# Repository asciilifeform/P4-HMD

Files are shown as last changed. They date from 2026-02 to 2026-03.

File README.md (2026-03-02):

# Interface Board and Linux Support for Reflection Technology's "Private Eye P4" electromechanical HMD.

This project allows connecting the [Private Eye P4 head-mounted display](https://www.loper-os.org/?p=752) to an RPI-compatible Linux machine via an FPGA interface [board](/pcb/p4_pcb.png).

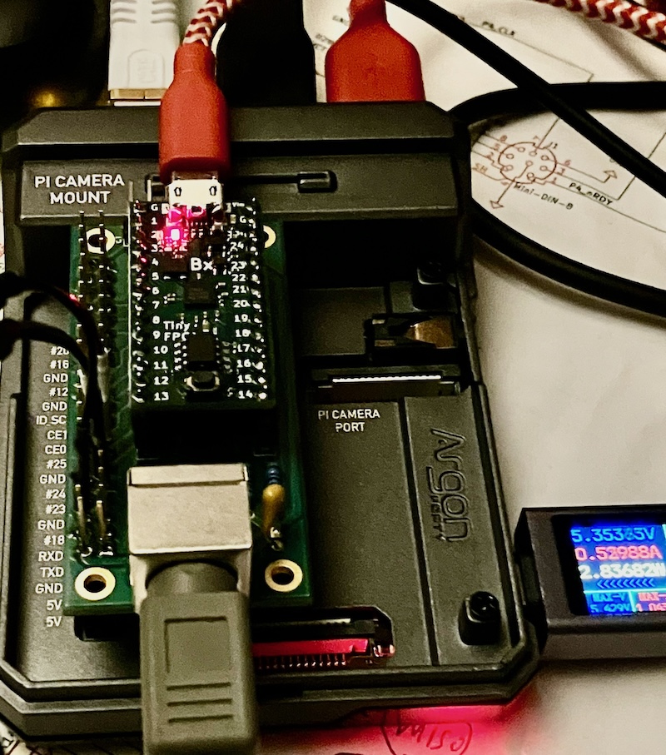
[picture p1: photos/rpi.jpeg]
Photo of Test Unit

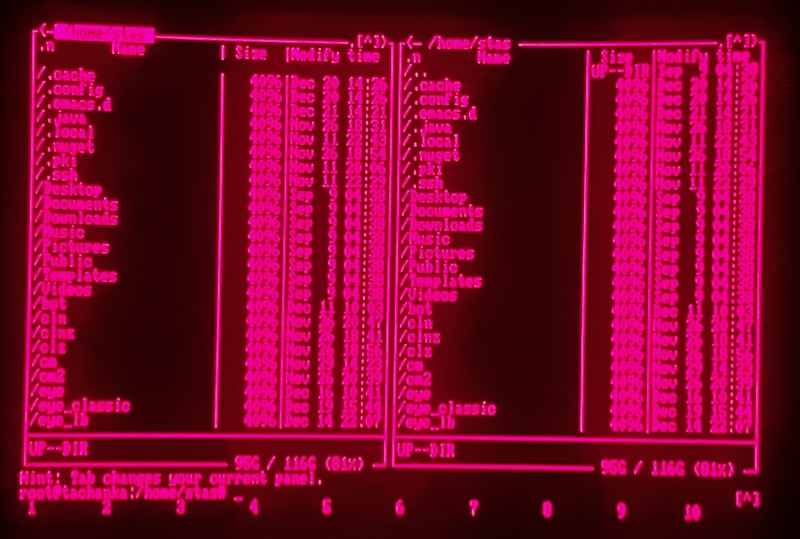
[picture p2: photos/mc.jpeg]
Midnight Commander seen through ocular


# You will need:

* The [Private Eye P4](/p4docs/p4.pdf) itself. (No, I don't know where you could get one. Sadly, it is entirely conceivable that I have the very last surviving unit.)
* An RPI or any similar machine with a compatible I/O pinout.
* [The interface PCB](/pcb/p4_schem.png) (I had 5 made for ~50 USD at JLC, but it's a 2-layer, so potentially hand-etchable. You will need the level shifter, passives, connectors (standard 2.54mm headers; as for the P4's data cable, the PCB footprint presumes [this](https://www.amazon.com/dp/B007PQ0ZG6) socket or its equivalent), and perhaps half an hour to solder.)
* A [TinyFPGA BX](https://www.crowdsupply.com/tinyfpga/tinyfpga-ax-bx) board (may be out of print now!) It is possible to use a different FPGA (you will need one with on-board SRAM) but then you will need to change certain things in the code, and, obviously, you will also need a different PCB.
* The code in this repo ([FPGA firmware](/fpga/) and [Linux kernel module](/kmod/).)

The display is 720x280 pixels but in fact natively rotated to 90 degrees, so it appears
as 280x720 to the hardware. The driver handles adjustable rotation, power management, brightness (1 bit!), RLE compression,
and differential updates. It may be used with xorg or in console mode. Refresh of the picture up to 30Hz is possible, though for small deltas it is in practice faster (we use run-length encoding in the FPGA and send only differences from the previous frame, when there was one.)

Animations look reasonable, and there is very little perceptible flicker, as the mirror actually vibrates at 50Hz, and at any given time, one entire 280-pixel column of the on-board framebuffer is always being displayed (rather than one pixel, and only during forward horizontal scan, as on e.g. a CRT refreshed at the same rate.) The 30Hz limit for full-frame updates comes from the maximum bit rate on the cable.

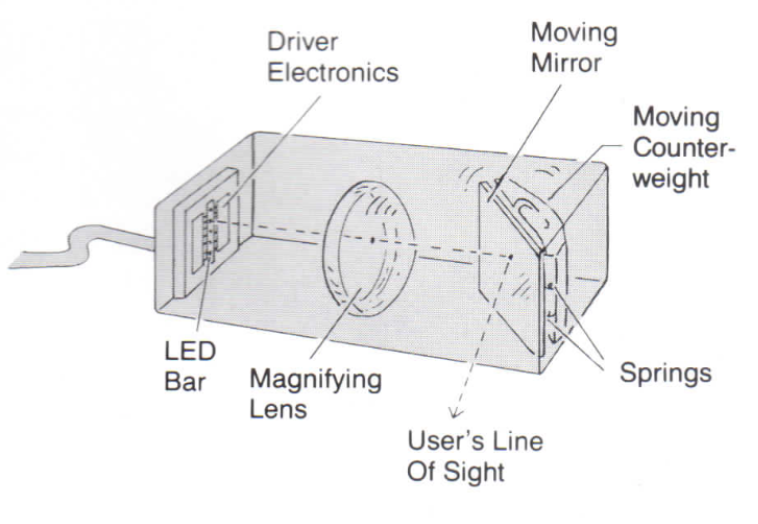
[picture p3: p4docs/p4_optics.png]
[](/p4docs/p4_optics.png)
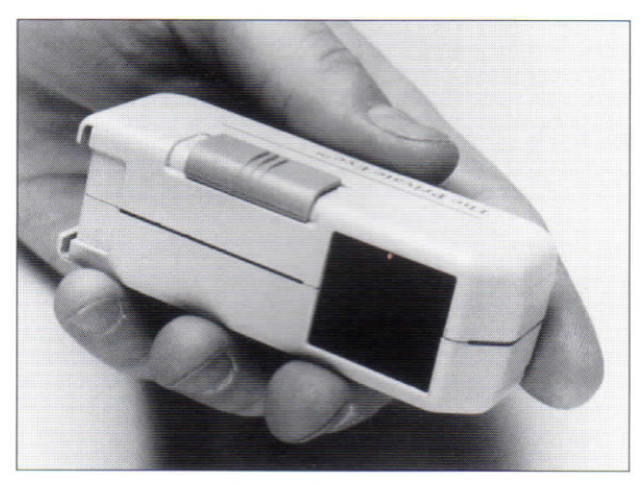
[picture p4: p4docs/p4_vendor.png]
[](/p4docs/p4_vendor.png)

# Caution

**The Linux kernel module and its documentation was generated entirely using an LLM!** It runs stably (including when unit is unplugged and replugged) but could contain bugs! Including exploitable bugs! Use at your own risk.

# Possibly-interesting aspects

* LLM ("Claude Opus 4.5", "Max" variant) required ~2000 prompts to produce the Linux kernel module for this device.
* The [Linux kernel driver](/kmod/) makes correct use of DMA and does not substantially burden the CPU. It works with the current kernel, and can be used with very modest irons. Maximum SPI speed is limited to ~25MHz by the board's I/O impedance, but this is unimportant, as the maximum bit rate at which the P4 is able to receive differential picture updates is 8MHz. The FPGA performs the necessary buffering and clock domain crossing.
* There is support for [powering down/waking](/kmod/dpms.c) and [dimming/undimming](/kmod/backlight.c) the P4, as well as rotation.
* Display [rotation](/kmod/rotation.c) [uses NEON instructions where available](/kmod/rotate_neon.c). (Confirmed to work on RPI4.)
* [Vblank](https://www.chiark.greenend.org.uk/doc/linux-doc-3.16/html/drm/drm-vertical-blank.html) is [handled](/kmod/vblank.c)! 
* The [FPGA firmware](/fpga/) (hand-written, builds on [Yosys](https://github.com/YosysHQ/yosys)) includes a working fully-[asynchronous SPI slave controller](/fpga/spi_slave_async.v) for the [iCE40](https://www.latticesemi.com/en/Products/FPGAandCPLD/iCE40) -- an item AFAIK not previously published anywhere.
* The iCE40 is clocked at 16MHz and no PLL are used. However, the controller can receive just short of 16kB of buffer data in one shot at up to 100MHz (definitely not supported on RPI! and not particularly useful, but possible!) as the SPI slave and FIFO receiver are asynchronous! They are clocked with the host-supplied SPI clock, without any oversampling.
* The picture quality is not adequately represented by the above photo, as the P4 is a persistence-of-vision device (it contains a vibrating mirror and a column of 280 micro-LEDs.) The contrast ratio and sharpness (though not the resolution or colour depth!) are IMHO well ahead of today's OLED glasses, even though the P4 was released in 1990!
* The P4 originally included a CGA-compatible 8-bit ISA interface card (I threw mine out, as it did not appear to work reliably even with period hardware, or rather with any such as I was able to unearth.)
* The [vendor docs](/p4docs/p4.pdf) hint that horizontal resolutions in excess of 720 columns may be available (the 32kB SRAM framebuffer installed in the P4 suggests that this may be true: the official resolution 720x280 uses only 25200 bytes), but I have not been able to discover a means for setting any useful undocumented modes. Certain values of the reserved command bits do appear to produce a corrupted image where the swing of the mirror clearly exceeds what is seen when using the standard resolution. It is in fact possible to send a full 32kB to the P4 (any more and it crashes/resets) -- but the extra bits do not appear anywhere in the visible picture.

# More about the Private Eye

* [Vendor brochure.](/p4docs/Private_Eye_Brochure.pdf)
* [Collection of original vendor docs](https://www.eventhorizons.com/projects/P4/p4.html) where I found the interface data sheet.
* [Museum exhibit.](https://artsandculture.google.com/asset/reflection-technology-private-eye-display/QgFnZtDAdVz0CQ?hl=en)
* A [paper](https://sid.onlinelibrary.wiley.com/doi/full/10.1002/j.2637-496X.1990.tb05924.x) by the designers.
* [Photos of prototype.](https://www.virtual-boy.com/images/972309/)
* [Article](https://arstechnica.com/gaming/2024/05/virtual-boy-the-bizarre-rise-and-quick-fall-of-nintendos-enigmatic-red-console/) about the "Virtual Boy", Nintendo's attempt at integrating the Private Eye into a game console. Before I purchased my P4 in 2004, I had obtained and barbarically destroyed a "Virtual Boy" in a failed attempt to create a usable PC HMD (don't do this! they're valuable antiques now. And the HMD optics are not usable without the intact plastic chassis; and similarly, the driving chipset is not cleanly separable from the rest of the Virtual Boy.)
* [My ancient parallel port interface to the P4.](https://www.loper-os.org/vintage/paralleleye/eye.html)

# License

The driver: SPDX-License-Identifier: GPL-2.0

The FPGA code and PCB are public domain.

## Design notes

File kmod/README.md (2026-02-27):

# P4 DRM Display Driver

DRM driver for the [Private Eye P4 head-mounted display](https://www.loper-os.org/?p=752) FPGA interface board connected via SPI.

The display is 720x280 pixels but mounted rotated 90 degrees, so it appears
as 280x720 to the hardware. The driver handles rotation, RLE compression,
and differential updates.

# Caution

The driver and the documentation was generated with the aid of LLMs!!!!!!! It runs stably (including when unit is unplugged and replugged) but may contain bugs! Including exploitable bugs! **All of the text below this point was bot-generated!!!**

## Requirements

- Linux kernel 6.x with DRM, SPI, and GPIO support
- ARM64 with NEON (for optimized rotation)
- Raspberry Pi 4 (or similar device with SPI and GPIO)

## Quick Start

```bash
# Build the module
make

# Run tests (userspace, no hardware needed)
make test

# Generate device tree overlay
make dtsi

# Load the driver
make load

# Unload the driver
make unload
```

## Hardware Setup

Edit `p4_pins.conf` to match your wiring:

```
SPI_BUS         = 0
SPI_CS          = 0
SPI_SPEED       = 28000000
GPIO_ENABLE     = 5
GPIO_READY      = 6
GPIO_NRESET     = 13
GPIO_COLD       = 22
GPIO_NSLEEP     = 17
GPIO_VSYNC      = 27
```

Then generate the device tree overlay:

```bash
make dtsi
```

## SPI Calibration

Before loading the driver for the first time, use the calibration tool to verify
connectivity and determine the optimal SPI speed:

```bash
# Build the calibration tool
make calibrate

# Run calibration (driver must NOT be loaded)
sudo ./p4_calibrate

# Test VSYNC signal
sudo ./p4_calibrate --vblank
```

The tool will:
1. Verify GPIO connectivity (NRESET, ENABLE, READY, COLD, NSLEEP - all required)
2. Ensure NSLEEP is deasserted (FPGA clock running) for calibration
3. Run handshake test (3 iterations):
   - Verify ENABLE/READY handshake
   - Verify COLD=1
   - Send clear packet, verify COLD falls to 0
   - Verify ENABLE/READY handshake again
   - Reset device, verify COLD rises to 1
3. If `--vblank`: measure VSYNC frequency (expects 40-70 Hz)
4. Test SPI echo at speeds from 1-50 MHz
5. Report the maximum reliable speed

The FPGA echoes SPI data when ENABLE is low: each byte sent on MOSI appears on
MISO delayed by one byte. The calibration tool uses this to detect corruption
at various speeds.

### Pattern Test Mode

The calibration tool can also send test patterns to verify the encoder and
transmission independently from the kernel driver:

```bash
# Send checkerboard pattern
sudo ./p4_calibrate --pattern checker

# Send 100 frames of animation
sudo ./p4_calibrate --pattern animate --frames 100

# With verbose packet output and bit reversal
sudo ./p4_calibrate --pattern checker --verbose --bitrev
```

Pattern types: `white`, `black`, `checker`, `vstripes`, `hstripes`, `gradient`, `animate`

This mode uses the same packet encoder (`update.h`) as the driver, sending
properly formatted packets via SPI with edge-triggered READY signal handling.
Useful for debugging display issues without involving the kernel driver.

### Frame Sync Test

The `--test-frames` option verifies the FPGA's new_frame synchronization logic:

```bash
sudo ./p4_calibrate --test-frames
```

This test rapidly fills and clears screen regions using RLE packets. Each
iteration sends:
1. Fill region white with `new_frame=1` (triggers vblank presentation)
2. Clear region black with `new_frame=0` (does NOT trigger presentation)

If the new_frame logic works correctly, the clear operation completes before
the next vblank and the region appears solid white without flickering. The test
uses 1/4 screen regions (~6.3ms each at 8MHz) to stay well under the ~16ms
vblank period.

Example output:
```
P4 Display SPI Calibration Utility
===================================

Resetting device...
  ENABLE=0, READY=0: OK
  ENABLE=1, READY=1: OK
  COLD=1 after reset: OK
Device connectivity verified.

Testing ENABLE/READY handshake and COLD flag (3 iterations)...
  Iteration 1:
    ENABLE/READY handshake: OK
    COLD=1 before send_clear: OK
    send_clear packet sent: OK
    COLD=0 after send_clear: OK
    ENABLE/READY handshake: OK
    COLD=1 after reset: OK
  ...
Handshake and COLD flag behavior verified.

Discovering supported SPI speeds...
  Found 12 supported speeds (0.5 MHz - 62.5 MHz)

Testing SPI speeds...
  Testing   0.5 MHz... OK
  Testing   1.0 MHz... OK
  Testing   2.0 MHz... OK
  Testing   4.0 MHz... OK
  Testing   8.0 MHz... OK
  Testing  28.0 MHz... OK
  Testing  32.0 MHz... ERRORS

===================================
Maximum reliable SPI speed: 28000000 Hz (28.0 MHz)

Recommendation: Update p4_pins.conf:
  SPI_SPEED = 28000000
===================================
```

Update `p4_pins.conf` with the recommended speed before loading the driver.

## Build Targets

| Target | Description |
|---|---|
| `make` | Build kernel module (debug enabled by default) |
| `make P4_DEBUG=0` | Build production (minimal logging) |
| `make P4_DEBUG=1 P4_DEBUG_VERBOSE=1` | Build with verbose logging |
| `make test` | Build and run userspace tests (115 tests) |
| `make calibrate` | Build SPI calibration tool |
| `make dtsi` | Generate device tree overlay from p4_pins.conf |
| `make load` | Load overlay and module |
| `make unload` | Unload module and overlay |
| `make fire` | Crash-safe loading with logging and test patterns |
| `make install` | Install module and overlay for loading on boot |
| `make uninstall` | Remove installed module and overlay |
| `make check-syntax` | Flymake syntax checking (see below) |
| `make patch` | Generate in-tree kernel patch |
| `make clean` | Clean build artifacts |

## Installation for Boot

To install the driver so it loads automatically on boot:

```bash
# Build and install (requires root)
make
sudo make install
```

This will:
1. Install the kernel module to `/lib/modules/$(uname -r)/`
2. Run `depmod -a` to update module dependencies
3. Install the device tree overlay to `/boot/overlays/`
4. Create `/etc/modules-load.d/drm_p4.conf` for auto-loading

After installation, add to `/boot/config.txt` (or `/boot/firmware/config.txt`):

```
dtoverlay=p4_display
```

Then reboot.

To uninstall:

```bash
sudo make uninstall
# Remove dtoverlay=p4_display from /boot/config.txt
# Reboot
```

## Crash-Safe Debugging (`make fire`)

For debugging crashes, `make fire` will:

1. Rebuild everything
2. Clear dmesg and enable full DRM debug output
3. Load the driver in the background
4. Stream dmesg to both terminal and timestamped log file
5. Send test patterns to the display periodically (logged)
6. Sync each line to disk immediately (survives crashes)
7. Clean up when you Ctrl-C

```bash
make fire
# Watch output... Ctrl-C when done
# Log saved to p4_fire_YYYYMMDD_HHMMSS.log
```

If the machine crashes, check the log file after reboot for debug output
up to the crash point.

## Test Patterns

Generate and display test patterns:

```bash
# Generate all patterns to files
./gen_patterns.py

# List available patterns
./gen_patterns.py --list

# Send a pattern directly to the display
./gen_patterns.py --pattern checkerboard > /dev/fb1

# Or generate files first, then send
./gen_patterns.py
cat pattern_checkerboard.raw > /dev/fb1
```

Available patterns:
- `white` - All white (0x00)
- `black` - All black (0xFF)
- `checkerboard` - 8x8 pixel checkerboard
- `hstripes` - Horizontal stripes (8px)
- `vstripes` - Vertical stripes (8px)
- `gradient_h` - Horizontal gradient (dithered)
- `gradient_v` - Vertical gradient (dithered)
- `grid` - Single-pixel grid lines every 8 pixels

## Flymake Support (Emacs)

For syntax checking in Emacs with flymake:

```bash
# Native compilation
make check-syntax CHK_SOURCES=sender.c

# Cross-compile for ARM64
make check-syntax CHK_SOURCES=sender.c CROSS_COMPILE=aarch64-linux-gnu-

# Custom kernel headers location
make check-syntax CHK_SOURCES=sender.c KERNEL_HEADERS=/path/to/linux/include

# Minimal mode (headers only, no full kernel tree)
make check-syntax CHK_SOURCES=sender.c \
    KERNEL_HEADERS_ONLY=1 \
    KERNEL_HEADERS=/path/to/headers
```

Add to your Emacs config:

```elisp
(setq flymake-cc-command "make check-syntax CHK_SOURCES=")
```

## In-Tree Kernel Patch

To generate a patch suitable for kernel submission:

```bash
make patch
```

This creates `p4-display-driver.patch` containing all source files
(except tests.c) in `drivers/gpu/drm/p4/` format with proper
Makefile and Kconfig.

To apply:

```bash
cd /path/to/linux
patch -p1 < p4-display-driver.patch
```

Then add to `drivers/gpu/drm/Makefile`:

```makefile
obj-$(CONFIG_DRM_P4) += p4/
```

And to `drivers/gpu/drm/Kconfig`:

```
source "drivers/gpu/drm/p4/Kconfig"
```

## Module Structure

```
drm_p4_main.c      - DRM callbacks, probe/remove
├── sender.c       - SPI, GPIO, FIFO, drainer thread
├── vblank.c       - vsync IRQ handling with watchdog
├── backlight.c    - Brightness control (0=blank, 1=dim, 2=full)
├── sleep.c        - suspend/resume coordination
├── dpms.c         - power management states
├── rotation.c     - 90° block rotation (scalar)
├── rotate_neon.c  - 90° block rotation (NEON optimized)
└── update.c       - RLE encoding, diff detection, packet generation

drm_boilerplate.h  - DRM connector/pipe/driver structs
p4.h               - Shared definitions, device struct
types.h            - Portable type definitions
display.h          - Display dimensions and timing constants
bitrev.h           - Bit reversal primitive
rotation_ops.h     - Rotation primitives (gather, scatter, transpose)
```

## Protocol

The driver communicates with the display via SPI packets. Each packet has a
command byte followed by type-specific fields.

### Command Byte (first byte of every packet)

```
Bit 7: rle        - Data is RLE encoded (single byte repeated)
Bit 6: new_frame  - First packet of a new frame
Bit 5: bitrev     - Bit-reverse data bytes (FPGA-selectable)
Bits 4..3: reserved (zero)
Bits 2..1: cmd_len - Bytes following cmd before len/data (0, 1, or 3)
Bit 0: always 1
```

### Packet Types

**Flags-only (cmd_len=1, cmd=0x03)** - Update display flags without data:
```
[0x03] [flags]
```
Header size: 2 bytes. Used for DPMS/backlight state changes.

**Data (cmd_len=3, cmd=0x07)** - Data at arbitrary address with flags:
```
[0x07] [flags] [addr_hi] [addr_lo] [len_lo] [len_hi] [data...]
```
Header size: 6 bytes. Used for full refreshes and differential updates.

Note: The cmd byte values shown are base values. OR in 0x80 for RLE, 0x40 for
new_frame, 0x20 for bitrev. Example: RLE data packet with new_frame = 0xC7.

### Length Encoding

The 16-bit length field is shifted left by 1 bit on the wire (LSB of len_lo
is always 0). This gives a maximum payload length of 32767 bytes.

Wire format: `wire_len = len << 1`
Decode: `len = wire_len >> 1`

Example: length 25200 (0x6270) → wire 50400 (0xC4E0) → len_lo=0xE0, len_hi=0xC4

### Display Flags Byte

```
Bit 7: upside_down   - 180° hardware rotation
Bit 6: standby       - Deep sleep (pauses VSYNC)
Bit 5: blank         - Screen blank (fast resume, pauses VSYNC)
Bit 4: low_intensity - Half brightness
Bits 3..0: reserved (zero)
```

### Data Encoding

- **RLE packets** (rle=1): Single data byte repeated `len` times
- **Literal packets** (rle=0): `len` bytes of raw pixel data
- Address is in bytes (big-endian), length is in bytes (little-endian, shifted)
- Maximum packet data size: 4090 bytes (fits in 4KB device buffer with header)

### RLE Efficiency

The encoder uses RLE for runs of 8+ identical bytes. Packet overhead analysis:

| Run Length | Packet Size | Savings |
|---|---|---|
| 8 bytes | 7 bytes | 12.5% |
| 32 bytes | 7 bytes | 78% |
| 35 bytes (1 row) | 7 bytes | 80%  |
| 25206 bytes (full screen) | 7 bytes | 99.97% |

Each RLE packet has 6-byte header + 1-byte value = 7 bytes total. This means:
- 8-byte runs barely break even (RLE_MIN_RUN threshold)
- Longer runs yield dramatically better compression
- Solid screens compress to just 7 bytes regardless of size

Corner cases (solid screen with disruptions):
- 1 corner pixel changed: ~14 bytes total
- 4 corner pixels changed: ~49 bytes total

### Packet Selection

The encoder automatically selects the optimal packet type:
- Image data → data packet with flags and address
- Flag changes only → flags-only packet

## DPMS / Power States

The driver supports fbdev blanking via the DPMS subsystem. Power states are
managed through `p4_set_power_mode()` which sets mutually exclusive flags:

| Mode | Flags | NSLEEP | Behavior |
|---|---|---|---|
| `P4_POWER_NORMAL` | all clear | High | Full power, VSYNC active |
| `P4_POWER_LOW` | low_intensity=1 | High | Dim display (half brightness) |
| `P4_POWER_BLANK` | blank=1 | High | Screen blank, fast resume |
| `P4_POWER_OFF` | standby=1 | Low* | Deep sleep, FPGA clock stopped |

*NSLEEP is only asserted in `FB_BLANK_POWERDOWN`, not `FB_BLANK_VSYNC_SUSPEND`.

### DPMS State Mapping

| FB Blank State | Power Mode | Notes |
|---|---|---|
| `FB_BLANK_UNBLANK` | `P4_POWER_NORMAL` | Respects brightness ceiling |
| `FB_BLANK_NORMAL` | `P4_POWER_BLANK` | Screen off, fast resume |
| `FB_BLANK_VSYNC_SUSPEND` | `P4_POWER_OFF` | Deep sleep |
| `FB_BLANK_POWERDOWN` | `P4_POWER_OFF` | Deep sleep + NSLEEP asserted |

### Brightness and Power Interaction

The backlight subsystem controls brightness via `p4_set_brightness()`:
- **Level 0**: Blank (screen off)
- **Level 1**: Low intensity (dim)
- **Level 2**: Full intensity (default)

Brightness changes are ignored while the display is in standby (DPMS off).
The `target_power` from before powerdown is preserved and restored on wake.

This means if the display was at full brightness when it went to sleep, it
will wake up at full brightness regardless of any brightness change attempts
while sleeping.

## Hotplug Support

The driver detects display disconnect/reconnect events and reports them to
userspace via DRM hotplug events. This allows X11/Wayland compositors to
automatically switch to other displays when the P4 is unplugged.

### Detection Mechanism

**Disconnect:** When the READY signal times out during a transfer, the drainer
thread marks the display as disconnected and sends a hotplug event.

**Reconnect:** When READY rises again after being offline, the driver debounces
(50ms), resets the device, and sends a hotplug event.

### DRM Connector Behavior

| State | connector_detect() | get_modes() |
|---|---|---|
| Connected | connected | 1 mode (720x280) |
| Disconnected | disconnected | 0 modes |

The CRTC atomic_check rejects enabling when disconnected (returns -ENODEV),
but allows disabling. This follows the DRM DP MST pattern and ensures X11
can cleanly tear down the display pipeline.

### VSYNC Behavior

When the display is disconnected, VSYNC signals stop (no display to sync with).
The vblank watchdog recognizes disconnected state and suppresses warnings.

## User Flip (180° Rotation)

The driver supports a user-controlled 180° flip that is independent of the DRM
rotation property. This allows switching orientation without affecting X11/Wayland
rotation settings - useful for head-mounted displays that can be used with either eye.

### Runtime Control

```bash
# Read current state
cat /sys/bus/spi/devices/spi*.0/user_flip

# Flip the display 180°
echo 1 | sudo tee /sys/bus/spi/devices/spi*.0/user_flip

# Return to normal
echo 0 | sudo tee /sys/bus/spi/devices/spi*.0/user_flip
```

### Boot-Time Configuration

Set `UPSIDE_DOWN = 1` in `p4_pins.conf` and regenerate the device tree overlay:

```bash
# Edit p4_pins.conf
UPSIDE_DOWN = 1

# Regenerate overlay
make dtsi
```

Or manually add `upside-down;` to the device tree overlay.

### Interaction with xrandr

The user flip is XORed with the DRM rotation:
- User flip = 0, xrandr normal → normal display
- User flip = 1, xrandr normal → 180° flipped
- User flip = 0, xrandr inverted → 180° flipped
- User flip = 1, xrandr inverted → normal display (flips cancel)

This allows:
- Changing user flip without disrupting X11 rotation settings
- X11 rotation changes work as expected
- User flip persists across X11 start/stop

## GPIO Signals

| Signal | Direction | Active | Description |
|---|---|---|---|
| ENABLE | Output | High | Assert during SPI transfer |
| READY | Input | High | High when device can accept data |
| NRESET | Output | Low | Active-low hardware reset |
| COLD | Input | High | High after reset until first data received |
| NSLEEP | Output | Low | Active-low FPGA sleep (stops clock when asserted) |
| VSYNC | Input | High | Hardware vblank signal |

**Note on DT GPIO flags:** All GPIOs use flag=0 in the device tree. The driver
uses physical values (0=low, 1=high) directly with gpiod, so NRESET and NSLEEP
are asserted by writing 0 and deasserted by writing 1.

The driver polls READY before each SPI transfer. If READY doesn't rise within
the timeout (600ms), the device is considered offline and the FIFO is flushed.

**Why 600ms?** The FPGA FIFO can hold ~4KB of data. In the worst case, this could
be filled with minimal 7-byte packets, each with `new_frame=1`. Since each
`new_frame` packet waits for a vblank (20ms at 50Hz), draining a full FIFO of
such packets could take up to 4096/7 × 20ms ≈ 585ms. The 600ms timeout provides
margin for this pathological case.

### NSLEEP Behavior

The NSLEEP pin controls the FPGA's clock. When driven low, the FPGA stops its
internal clock and enters a low-power state. The pin is externally pulled high.

NSLEEP is automatically managed by the driver:
- **Asserted (low)** after FIFO drains during system suspend or DPMS powerdown
- **Deasserted (high)** before any SPI communication on resume or DPMS powerup

During FPGA sleep, vblank interrupts are not generated and READY remains low.
The calibration tool ensures NSLEEP is deasserted before testing.

## Fakemode (Testing Without Hardware)

### Test Scripts

```bash
# Unit tests (no hardware needed)
make test                    # 115 algorithm tests

# FPS measurement
sudo ./test_fps.sh           # Measure frame rate
```

## Debug Output

### Log Levels

| Level | Build Command | Description |
|---|---|---|
| 0 | `make P4_DEBUG=0` | Production - only essential events |
| 1 | `make P4_DEBUG=1` | Debug (default) - state transitions |
| 2 | `make P4_DEBUG=1 P4_DEBUG_VERBOSE=1` | Verbose - per-vblank traces |

### Enable DRM Debug

```bash
# Enable DRM driver debug messages
echo 0x1ff | sudo tee /sys/module/drm/parameters/debug

# Enable dynamic debug for module
echo 'module drm_p4 +p' | sudo tee /sys/kernel/debug/dynamic_debug/control

# Follow output
dmesg -wT
```

### Always-On Messages (any build)

These appear in dmesg regardless of debug level:
- Probe success/failure
- Suspend/resume
- DPMS powerdown/powerup
- Device timeouts and recovery
- SPI errors

See `HARDWARE_TESTING.md` for full list.

## Files

| File | Description |
|---|---|
| `Makefile` | Out-of-tree build system |
| `Makefile.intree` | In-tree kernel Makefile (used by `make patch`) |
| `Kconfig` | Kernel config options (used by `make patch`) |
| `p4_pins.conf` | Pin configuration |
| `gen_dtsi.sh` | DTSI generator script |
| `gen_patterns.py` | Test pattern generator (stdout-based) |
| `fb_pattern.py` | Test pattern sender (mmap-based, preferred) |
| `verify_output.py` | Output verification script |
| `test_fps.sh` | FPS measurement script |
| `hw_test_suite.sh` | Hardware test suite |
| `p4_setmode.c` | Display rotation and pattern tool |
| `p4_calibrate.c` | SPI calibration and pattern test tool |
| `display.h` | Display dimensions and timing constants |
| `bitrev.h` | Bit reversal macro (shared) |
| `rotation_ops.h` | Rotation primitives (shared) |
| `tests.c` | Userspace test suite (not included in patch) |
| `CHANGELOG.md` | Version history and changes |
| `HARDWARE_TESTING.md` | Hardware testing guide |
| `README.md` | This file |

## License

SPDX-License-Identifier: GPL-2.0

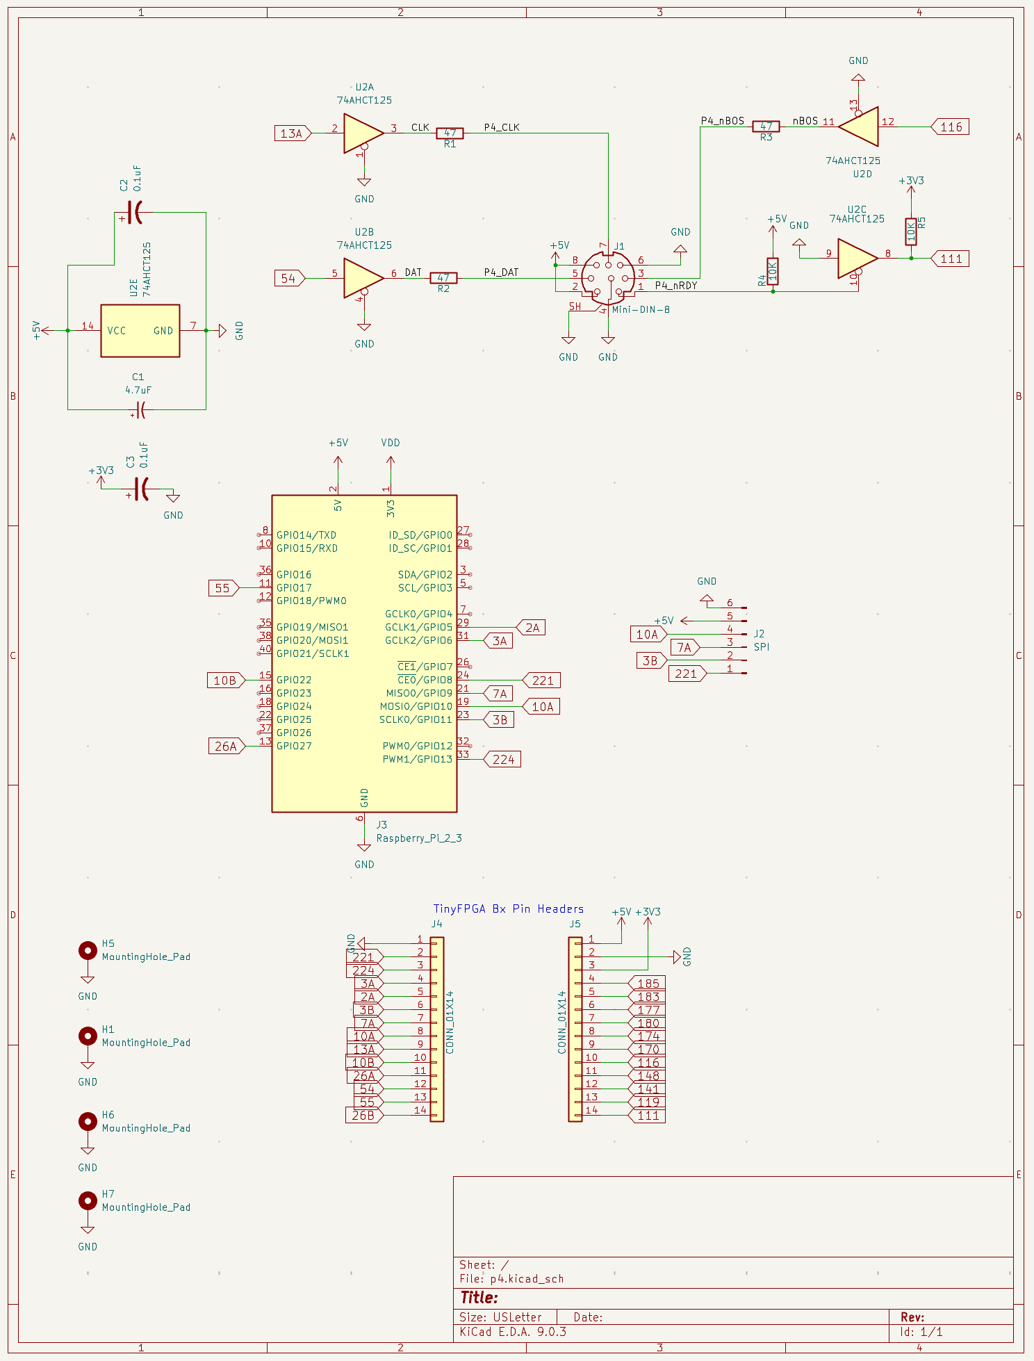
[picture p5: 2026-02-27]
pcb/p4_schem.png

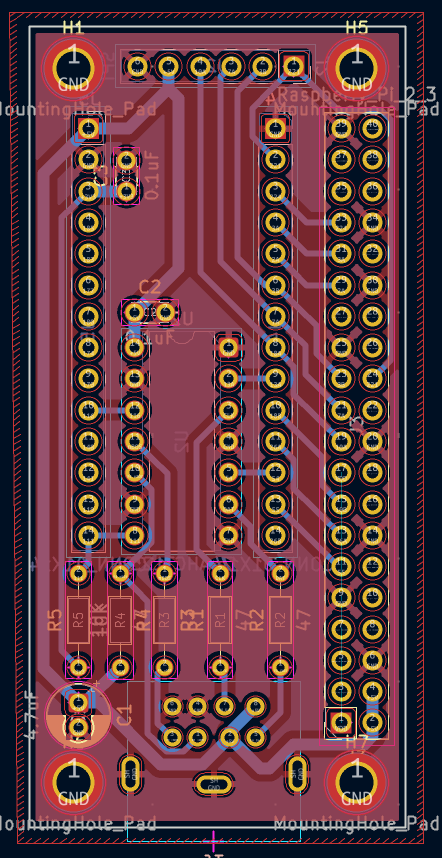
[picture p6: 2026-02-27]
pcb/p4_pcb.png

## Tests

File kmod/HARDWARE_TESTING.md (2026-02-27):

# P4 Display Driver - Hardware Testing Guide

## Pin Mapping

### Raspberry Pi Physical to BCM GPIO Translation

| RPi Physical Pin | BCM GPIO | Notes |
|---|---|---|
| Pin 3 | GPIO2 | I2C SDA |
| Pin 5 | GPIO3 | I2C SCL |
| Pin 7 | GPIO4 | GPCLK0 |
| Pin 8 | GPIO14 | UART TXD |
| Pin 10 | GPIO15 | UART RXD |
| Pin 11 | GPIO17 | |
| Pin 12 | GPIO18 | PCM CLK |
| Pin 13 | GPIO27 | |
| Pin 15 | GPIO22 | |
| Pin 16 | GPIO23 | |
| Pin 18 | GPIO24 | |
| Pin 19 | GPIO10 | SPI0 MOSI  |
| Pin 21 | GPIO9 | SPI0 MISO  |
| Pin 22 | GPIO25 | |
| Pin 23 | GPIO11 | SPI0 SCLK  |
| Pin 24 | GPIO8 | SPI0 CE0 |
| Pin 26 | GPIO7 | SPI0 CE1 |
| Pin 29 | GPIO5 | |
| Pin 31 | GPIO6 | |
| Pin 32 | GPIO12 | PWM0 |
| Pin 33 | GPIO13 | PWM1 |
| Pin 35 | GPIO19 | PCM FS |
| Pin 36 | GPIO16 | |
| Pin 37 | GPIO26 | |
| Pin 38 | GPIO20 | PCM DIN |
| Pin 40 | GPIO21 | PCM DOUT |

Power pins: 1, 17 (3.3V); 2, 4 (5V); 6, 9, 14, 20, 25, 30, 34, 39 (GND)

### Required Signals

The driver requires these signals (actual pin assignments are in the device tree):

| Signal | Direction | Description |
|---|---|---|
| SPI MOSI | Out | SPI data to display |
| SPI SCLK | Out | SPI clock |
| SPI CS | Out | SPI chip select |
| RESET | Out | Active low device reset |
| ENABLE | Out | Enable signal for transfers |
| READY | In | Device ready (rising edge IRQ) |
| COLD | In | Device needs full refresh |
| VSYNC | In | Optional hardware vsync (rising edge)  |

### Device Tree Configuration

Pin assignments are defined in `p4_display.dtsi`. Modify the `*-gpios` properties to match your wiring:

```dts
reset-gpios = <&gpio NN GPIO_ACTIVE_LOW>;
enable-gpios = <&gpio NN GPIO_ACTIVE_HIGH>;
ready-gpios = <&gpio NN GPIO_ACTIVE_HIGH>;
cold-gpios = <&gpio NN GPIO_ACTIVE_HIGH>;
vsync-gpios = <&gpio NN GPIO_ACTIVE_HIGH>;  /* optional */
```

## Building for Hardware

```bash
# Build the driver
make clean
make

# Or for in-tree build
make -C /lib/modules/$(uname -r)/build M=$(pwd) modules
```

## SPI Calibration (First-Time Setup)

Before loading the driver for the first time, run the calibration tool to verify
wiring and determine the optimal SPI speed:

```bash
# Build calibration tool
make calibrate

# Run (driver must NOT be loaded)
sudo ./p4_calibrate --verbose

# Test VSYNC signal (if GPIO_VSYNC is configured)
sudo ./p4_calibrate --vblank
```

The tool:
1. Loads spidev module temporarily
2. Opens `/dev/gpiochipN` (chardev interface, no sysfs required)
3. Verifies GPIO connectivity (ENABLE, READY, RESET, COLD - all required)
4. Runs handshake/COLD test 3 times:
   - Verify ENABLE/READY handshake
   - Verify COLD=1, send clear packet, verify COLD=0
   - Verify ENABLE/READY handshake again
   - Reset, verify COLD=1
5. If `--vblank`: measures VSYNC frequency (expects 40-70 Hz)
6. Discovers supported SPI speeds from the driver
7. Tests each speed with SPI echo
8. Reports maximum reliable speed
9. Cleans up (releases GPIO lines, unloads spidev)

**How SPI echo works:** When ENABLE is low, the FPGA echoes each byte received
on MOSI back on MISO, delayed by one byte. Corruption indicates the speed is
too high for your wiring.

Options:
- `--config FILE` - Use alternate config file (default: p4_pins.conf)
- `--verbose` - Show detailed mismatch information

If calibration fails at all speeds, check:
- Device power supply
- SPI wiring (MOSI, MISO, SCLK, CS)
- GPIO wiring (ENABLE, READY, RESET)

## Loading the Driver

```bash
# Load the module
sudo insmod drm_p4.ko

# Verify it loaded
lsmod | grep drm_p4
dmesg | tail -20

# Check DRM device created
ls -la /dev/dri/

# Disable fbcon to avoid conflicts
for vt in /sys/class/vtconsole/vtcon*/bind; do
    echo 0 | sudo tee "$vt"
done
```

## Debug Mode

### Log Levels

The driver has three log levels:

| Level | Build Command | What's Logged |
|---|---|---|
| 0 (production) | `make P4_DEBUG=0` | Only essential events: probe, suspend, resume, DPMS, timeouts, errors |
| 1 (debug) | `make P4_DEBUG=1` | Above + state transitions, full refresh, send_clear |
| 2 (verbose) | `make P4_DEBUG=1 P4_DEBUG_VERBOSE=1` | Above + per-vblank traces, warm retries |

### Building with Debug

```bash
# Production build (minimal logging)
make clean && make P4_DEBUG=0

# Debug build (default, recommended for testing)
make clean && make P4_DEBUG=1

# Verbose build (for deep debugging)
make clean && make P4_DEBUG=1 P4_DEBUG_VERBOSE=1
```

### Enabling Dynamic Debug

After loading, enable DRM debug output:

```bash
# Enable dynamic debug for the module
echo 'module drm_p4 +p' | sudo tee /sys/kernel/debug/dynamic_debug/control

# Enable all DRM debug categories
echo 0x1ff | sudo tee /sys/module/drm/parameters/debug
```

### Using the Hardware Test Suite

The test suite supports log level selection:

```bash
# Default (debug level 1)
./hw_test_suite.sh

# Production (no debug)
./hw_test_suite.sh --log-level 0

# Verbose (all traces)
./hw_test_suite.sh --log-level 2
```

### Kernel Log Messages

**Always logged (any build):**
- `registered /dev/dri/cardN (WxH @ Hz SPI)` - successful probe
- `removing` - driver removal
- `suspending` / `resuming` - power management
- `DPMS powerdown` / `DPMS powerup` - display power
- `READY timeout, waiting for device` - device not responding
- `device cold, resetting` - device was reset/replugged
- `device reconnected (was cold)` - recovery after replug
- `device ready (warm), retrying` - recovery from missed IRQ
- `SPI transfer error` - communication failure

Monitor debug output:
```bash
# Follow kernel messages
sudo dmesg -wH

# Or with timestamps
sudo dmesg -wT
```

## FPS Measurement

### Method 1: Using debugfs (if available)

```bash
# Check if packet counter exists
cat /sys/kernel/debug/p4/stats

# Monitor packets per second
watch -n 1 'cat /sys/kernel/debug/p4/stats'
```

### Method 2: Using dmesg timestamps

```bash
# Enable debug mode, then look for vblank/frame markers
sudo dmesg -wT | grep -E "(vblank|frame|send_diff)"
```

### Method 3: FPS test script

See `test_fps.sh`.

## Error Monitoring

### Watch for errors
```bash
sudo dmesg -wT | grep -iE "(error|fail|timeout|offline|cold|recover)"
```

### Common messages and meanings

| Message | Level | Meaning | Action |
|---|---|---|---|
| `registered /dev/dri/cardN` | info | Probe succeeded | Normal |
| `suspending` / `resuming` | info | Power state change | Normal |
| `DPMS powerdown` / `powerup` | info | Display power change | Normal |
| `READY timeout, waiting` | warn | Device not responding | Check wiring, will auto-retry |
| `device cold, resetting` | warn | Device was reset/replugged | Will auto-recover |
| `device reconnected (was cold)` | info | Recovered after replug | Normal recovery |
| `device ready (warm), retrying` | info | Missed IRQ, retrying | Normal recovery |
| `SPI transfer error` | error | SPI communication failed | Check wiring, SPI speed |
| `device not ready at probe` | warn | Device offline at load | Drainer will retry |
| `device not ready at resume` | warn | Device offline at wake | Drainer will retry |

## Basic Functionality Tests

### 1. Display a test pattern
```bash
# Using p4_setmode (recommended)
sudo ./p4_setmode normal --pattern checker

# Or using modetest (from libdrm)
modetest -M p4 -s 32:720x280 -P 31@32:720x280
```

### 2. Test all rotations
```bash
for rot in normal left right inverted; do
    sudo ./p4_setmode $rot --pattern arrow
    sleep 1
done
```

### 3. Hardware stress test
```bash
sudo ./hw_test_suite.sh
```

## Performance Tuning

### SPI Speed
The default SPI speed is set in the device tree. To test different speeds:

```bash
# Check current speed
cat /sys/class/spi_master/spi0/spi0.0/max_speed_hz

# Typical values: 8000000 (8MHz), 28000000 (28MHz), 32000000 (32MHz)
```

### Vblank Rate
Software vblank runs at 50Hz. Hardware vsync uses the display's native rate.

## Troubleshooting

### No display output
1. Check module loaded: `lsmod | grep drm_p4`
2. Check DRM device: `ls /dev/dri/card*`
3. Check dmesg for errors: `dmesg | grep -i p4`
4. Verify SPI is enabled: `ls /dev/spidev*`

### Garbled display
1. Check SPI speed (may be too fast)
2. Verify bit order (bitrev flag)
3. Check rotation setting matches physical orientation

### Framebuffer Byte Order and Orientation

The hardware framebuffer is 280×720 pixels (35 bytes × 720 rows = 25,200 bytes).

**Byte 0** corresponds to the **top-left 8 pixels** (row 0, columns 0-7) when viewing
the display in portrait orientation (280 wide × 720 tall). In the arrow test pattern,
this is where the vertical bar marker appears.

Byte layout:
- Byte 0: row 0, pixels 0-7 (top-left)
- Byte 34: row 0, pixels 272-279 (top-right)
- Byte 35: row 1, pixels 0-7
- Byte 25165: row 719, pixels 0-7 (bottom-left)
- Byte 25199: row 719, pixels 272-279 (bottom-right)

Within each byte, **MSB-first** ordering: bit 7 = leftmost pixel, bit 0 = rightmost.

**If the display appears mirrored:**
- Horizontal flip: reverse bit order within bytes (toggle bitrev flag)
- Vertical flip: reverse row order
- 180° rotation: both of the above

The arrow pattern (`p4_setmode normal --pattern arrow`) has distinct corner markers
to help diagnose orientation issues:
- TL (in portrait): vertical bar (16×48)
- TR (in portrait): square (~24×24 or ~40×40)
- BL (in portrait): square (~40×40 or ~24×24)
- BR (in portrait): horizontal bar (48×16)

### Display freezes
1. Check READY pin connection
2. Monitor for timeout errors in dmesg
3. Check if device went offline (should auto-recover)

### Kernel panic / oops
1. Check dmesg for stack trace
2. Verify kernel headers match running kernel
3. Try with debug build for more info

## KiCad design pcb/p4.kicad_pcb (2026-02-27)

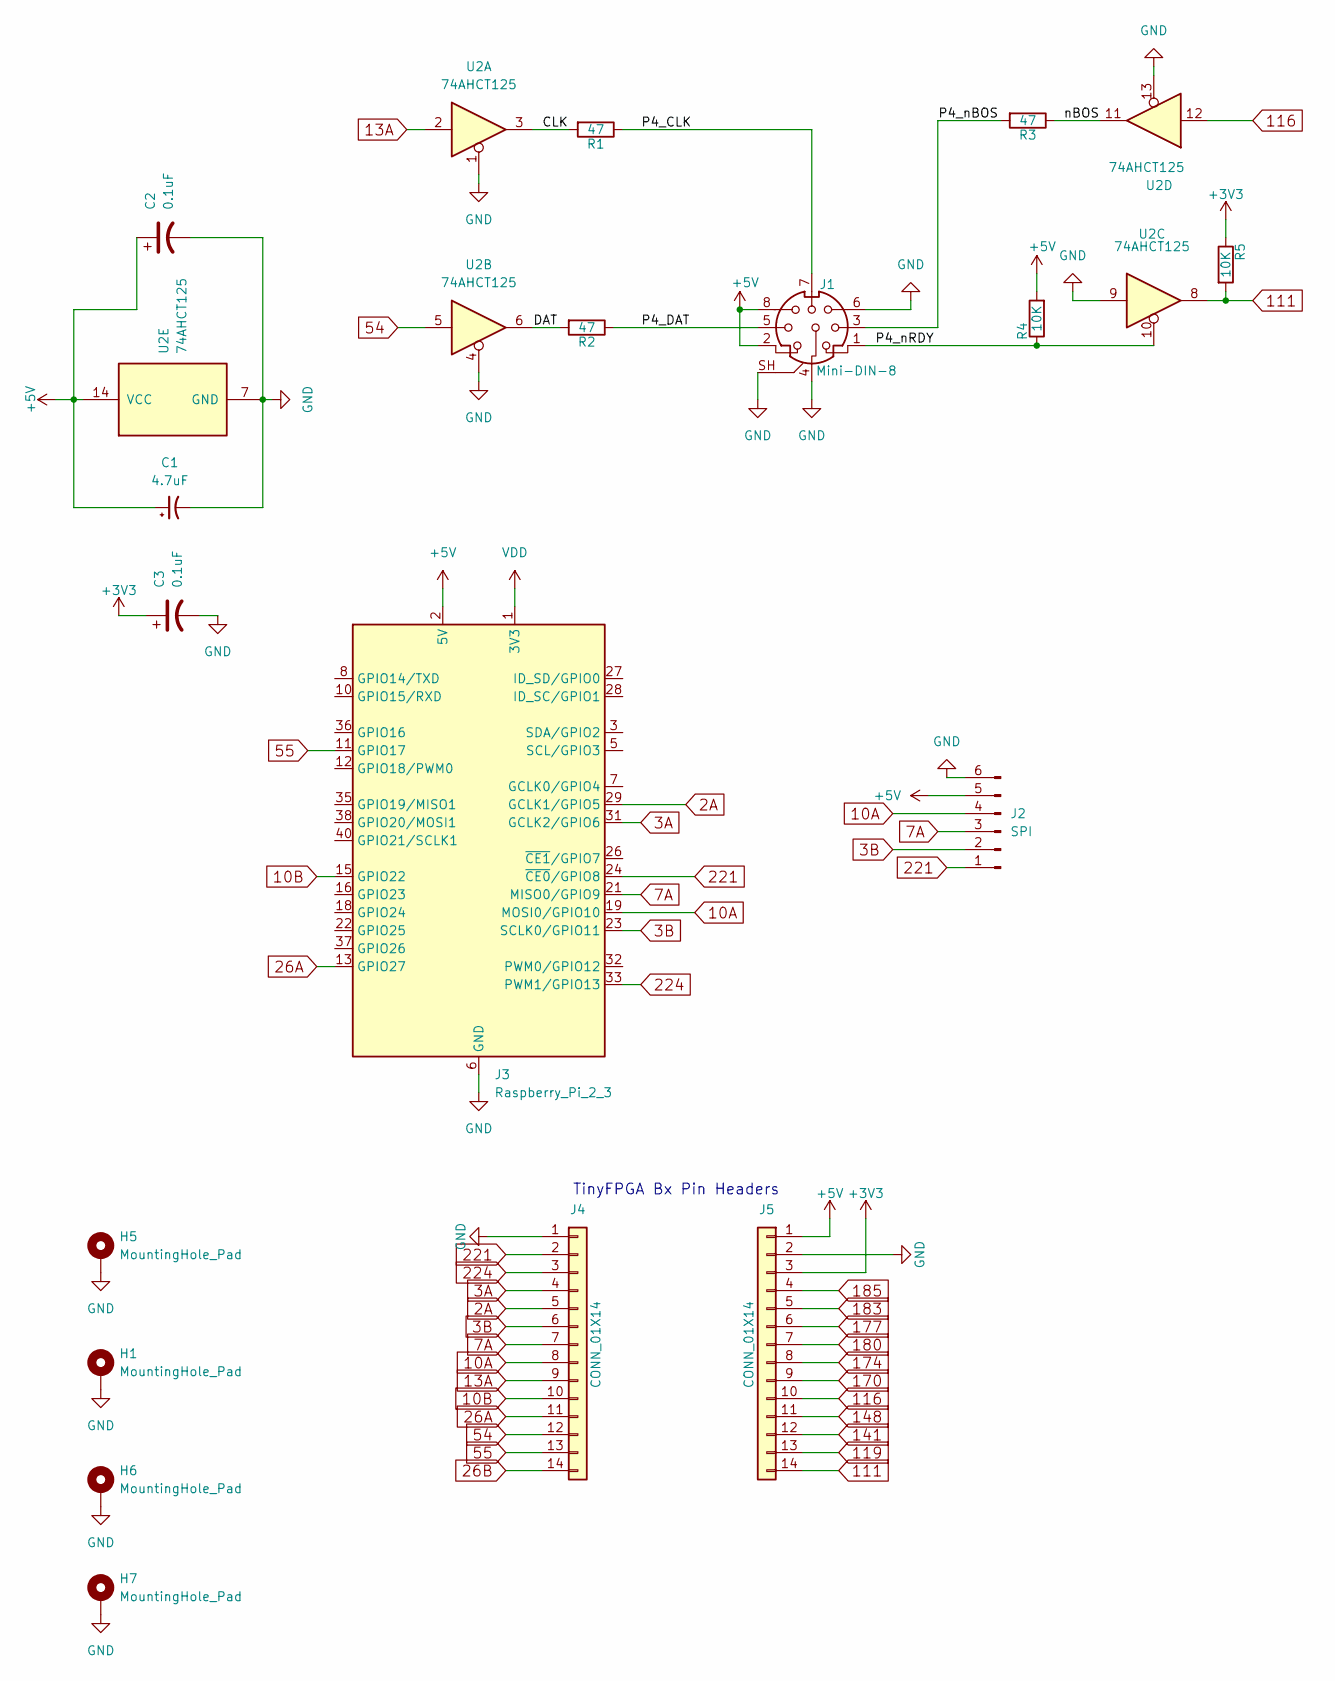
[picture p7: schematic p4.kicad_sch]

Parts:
C1: 4.7uF; CP_Radial_D5.0mm_P2.00mm
C2, C3: 0.1uF; C_Disc_D3.0mm_W1.6mm_P2.50mm
H1, H5, H6, H7: MountingHole_Pad; MountingHole_2.7mm_M2.5_DIN965_Pad
J1: Mini-DIN-8; Mini_DIN_round_8_canned
J2: SPI; PinHeader_1x06_P2.54mm_Vertical
J3: Raspberry_Pi_2_3; PinSocket_2x20_P2.54mm_Vertical
J4, J5: CONN_01X14; PinHeader_1x14_P2.54mm_Vertical
R1, R2, R3: 47; R_Axial_DIN0204_L3.6mm_D1.6mm_P7.62mm_Horizontal
R4, R5: 10K; R_Axial_DIN0204_L3.6mm_D1.6mm_P7.62mm_Horizontal
U2: 74AHCT125; DIP-14_W7.62mm

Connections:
2A: J3.29 (GCLK1/GPIO5), J4.5
3A: J3.31 (GCLK2/GPIO6), J4.4
3B: J2.2, J3.23 (SCLK0/GPIO11), J4.6
7A: J2.3, J3.21 (MISO0/GPIO9), J4.7
10A: J2.4, J3.19 (MOSI0/GPIO10), J4.8
10B: J3.15 (GPIO22), J4.10
13A: J4.9, U2.2
26A: J3.13 (GPIO27), J4.11
26B: J4.14
54: J4.12, U2.5
55: J3.11 (GPIO17), J4.13
111: J5.14, R5.2, U2.8
116: J5.10, U2.12
119: J5.13
141: J5.12
148: J5.11
170: J5.9
174: J5.8
177: J5.6
180: J5.7
183: J5.5
185: J5.4
221: J2.1, J3.24 (~CE0/GPIO8), J4.2
224: J3.33 (PWM1/GPIO13), J4.3
+3V3: C3.1, J5.3, R5.1
+5V: C1.1, C2.1, J1.2, J1.8, J2.5, J3.2 (5V), J3.4 (5V), J5.1, R4.2, U2.14 (VCC)
/CLK: R1.2, U2.3
/DAT: R2.2, U2.6
/P4_CLK: J1.7, R1.1
/P4_DAT: J1.5, R2.1
/P4_nBOS: J1.3, R3.2
/P4_nRDY: J1.1, R4.1, U2.10
/nBOS: R3.1, U2.11
GND: C1.2, C2.2, C3.2, H1.1, H5.1, H6.1, H7.1, J1.4, J1.6, J1.SH, J2.6, J3.6 (GND), J3.9 (GND), J3.14 (GND), J3.20 (GND), J3.25 (GND), J3.30 (GND), J3.34 (GND), J3.39 (GND), J4.1, J5.2, U2.1, U2.4, U2.7 (GND), U2.9, U2.13
VDD: J3.1 (3V3), J3.17 (3V3)

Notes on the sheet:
TinyFPGA Bx Pin Headers

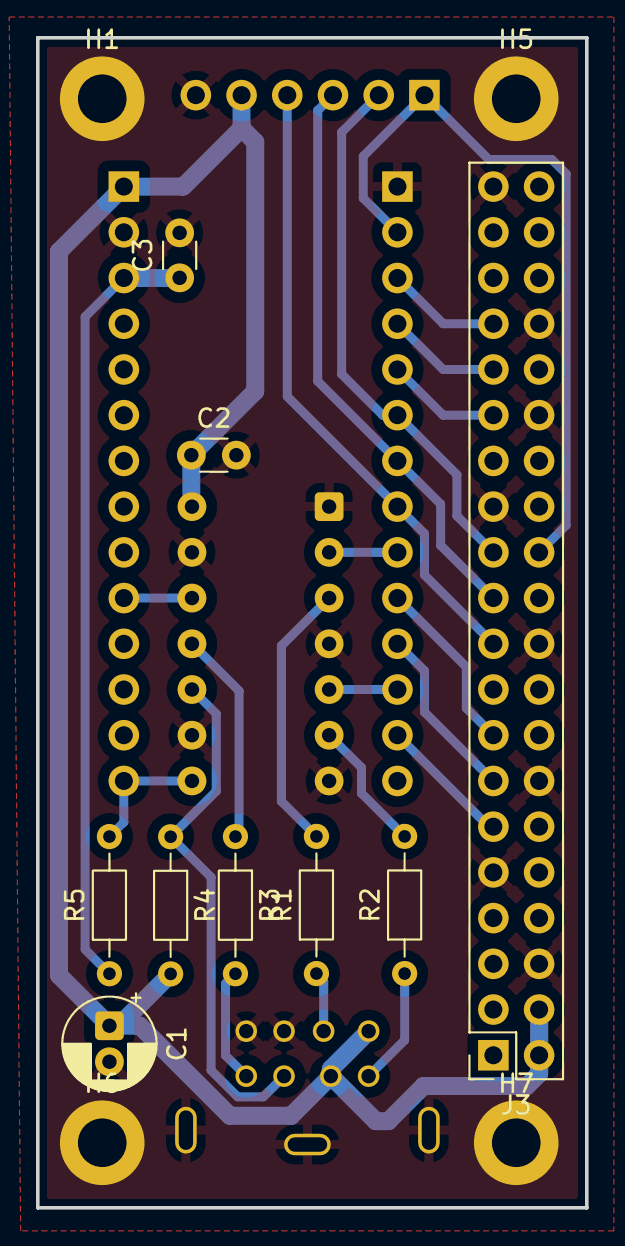
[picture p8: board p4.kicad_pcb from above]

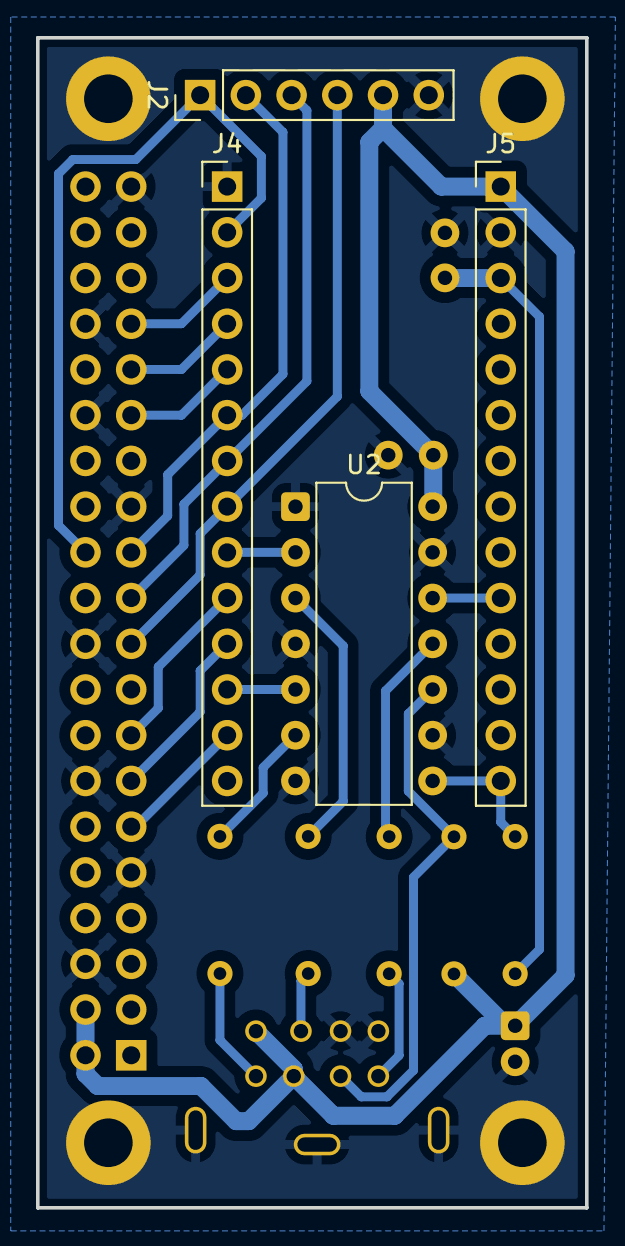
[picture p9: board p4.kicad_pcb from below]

Board: 2 copper layers, 30.5 x 65.0 mm, 18 parts (5 on the bottom side), 25 nets.

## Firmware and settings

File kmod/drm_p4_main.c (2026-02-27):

// SPDX-License-Identifier: GPL-2.0
/*
 * DRM driver for P4 rotated monochrome SPI display
 * Display: 720x280 or 280x720 (userspace) -> 280x720 (hardware)
 */

#include <linux/crc32.h>
#include <linux/fb.h>
#include <linux/of.h>

#include <drm/drm_atomic_helper.h>
#include <drm/drm_blend.h>
#include <drm/drm_damage_helper.h>
#include <drm/drm_fb_dma_helper.h>
#include <drm/drm_fbdev_dma.h>
#include <drm/drm_format_helper.h>
#include <drm/drm_fourcc.h>
#include <drm/drm_framebuffer.h>
#include <drm/drm_gem_atomic_helper.h>
#include <drm/drm_gem_dma_helper.h>
#include <drm/drm_gem_framebuffer_helper.h>
#include <drm/drm_managed.h>
#include <drm/drm_probe_helper.h>
#include <drm/drm_vblank.h>

#include "p4.h"
#include "sender.h"
#include "vblank.h"
#include "backlight.h"
#include "sleep.h"
#include "drm_boilerplate.h"

/* Module parameter for full SPI hex dump */
static bool hexdump;
module_param(hexdump, bool, 0644);
MODULE_PARM_DESC(hexdump, "Dump full SPI transfers to dmesg (default: 0)");

/*
 * Process a damage clip in ROTATED mode (720x280 userspace).
 * Convert XRGB8888 to mono, then rotate 90° to destination.
 */
static void p4_process_clip_rotated(struct p4_device *p4,
				    const struct iosys_map *src_map,
				    struct drm_framebuffer *fb,
				    const struct drm_rect *clip,
				    struct drm_format_conv_state *fmtcnv,
				    int dst_idx)
{
	struct iosys_map dst_map;
	unsigned int fb_width = fb->width;
	unsigned int fb_height = fb->height;

	/*
	 * Align clip to 8-pixel boundaries for rotation.
	 * The rotation works on 8x8 blocks, so we need the mono conversion
	 * to include complete blocks.
	 */
	struct drm_rect aligned = {
		.x1 = clip->x1 & ~7,
		.y1 = clip->y1 & ~7,
		.x2 = (clip->x2 + 7) & ~7,
		.y2 = (clip->y2 + 7) & ~7,
	};
	/* Clamp to frame bounds */
	if (aligned.x2 > fb_width)
		aligned.x2 = fb_width;
	if (aligned.y2 > fb_height)
		aligned.y2 = fb_height;

	int bx1 = aligned.x1 >> 3;
	int bx2 = aligned.x2 >> 3;
	int by1 = aligned.y1 >> 3;
	int by2 = aligned.y2 >> 3;
	int clip_width_blocks = bx2 - bx1;

	/* Sanity check: blocks should be non-empty */
	if (bx1 >= bx2 || by1 >= by2)
		return;

	iosys_map_set_vaddr(&dst_map, p4->src_buf);

	/*
	 * Convert to mono (into src_buf) using aligned clip.
	 *
	 * IMPORTANT: drm_fb_xrgb8888_to_mono() ALWAYS writes starting at
	 * dst[0].vaddr (offset 0), regardless of clip position. The clip
	 * only controls which source pixels are read. Output is written
	 * as a compact block: clip_width_blocks bytes per line, with lines
	 * contiguous (when dst_pitch=NULL) or spaced by dst_pitch.
	 *
	 * For rotation to work correctly, we need the mono data laid out
	 * with the clip's stride (clip_width_blocks bytes per row).
	 * Pass NULL for pitch to get tightly packed output.
	 */
	drm_fb_xrgb8888_to_mono(&dst_map, NULL, src_map, fb, &aligned, fmtcnv);

	/*
	 * Rotate from src_buf to dst_buf.
	 *
	 * The mono data is at src_buf[0] with stride = clip_width_blocks.
	 * We need to rotate this data to the correct position in dst_buf.
	 *
	 * We pre-offset the source pointer so rotation reads from the right place:
	 *   src_offset = src_buf - (by1 * 8 * clip_width_blocks) - bx1
	 */
	unsigned int src_stride = clip_width_blocks;
	const u8 *src_offset = p4->src_buf - (by1 * 8 * src_stride) - bx1;

	rotate_blocks(src_offset, p4->dst_buf[dst_idx],
		      src_stride, fb_height >> 3, fb_width >> 3,
		      bx1, bx2, by1, by2);
}

/*
 * Process a damage clip in NATIVE mode (280x720 userspace).
 * Convert XRGB8888 to mono directly - no rotation needed.
 */
static void p4_process_clip_native(struct p4_device *p4,
				   const struct iosys_map *src_map,
				   struct drm_framebuffer *fb,
				   const struct drm_rect *clip,
				   struct drm_format_conv_state *fmtcnv,
				   int dst_idx)
{
	struct iosys_map dst_map;
	unsigned int fb_width = fb->width;
	unsigned int fb_height = fb->height;
	unsigned int dst_pitch = HW_WIDTH / 8;  /* 35 bytes */

	/*
	 * Align x to 8-pixel boundaries (byte alignment for mono).
	 * y doesn't need alignment in native mode.
	 */
	struct drm_rect aligned = {
		.x1 = clip->x1 & ~7,
		.y1 = clip->y1,
		.x2 = (clip->x2 + 7) & ~7,
		.y2 = clip->y2,
	};
	/* Clamp to frame bounds */
	if (aligned.x2 > fb_width)
		aligned.x2 = fb_width;
	if (aligned.y2 > fb_height)
		aligned.y2 = fb_height;

	/*
	 * In native mode, we write directly to dst_buf.
	 * Hardware layout: 280 pixels wide = 35 bytes per row, 720 rows.
	 *
	 * drm_fb_xrgb8888_to_mono() writes to dst starting at offset
	 * (clip.y1 * dst_pitch + clip.x1/8) when dst_pitch is provided.
	 * So we pass the base of dst_buf and the hardware pitch.
	 */
	iosys_map_set_vaddr(&dst_map, p4->dst_buf[dst_idx]);

	drm_fb_xrgb8888_to_mono(&dst_map, &dst_pitch, src_map, fb, &aligned, fmtcnv);

	/*
	 * The kernel's drm_fb_xrgb8888_to_mono() outputs LSB-first bit ordering
	 * (bit 0 = leftmost pixel), but hardware expects MSB-first (bit 7 =
	 * leftmost). We set the bitrev flag in cmd_byte so FPGA reverses bits
	 * in payload bytes - no software conversion needed here.
	 */
}

/*
 * Process a damage clip using the current rotation mode.
 */
static void p4_process_clip(struct p4_device *p4, const struct iosys_map *src_map,
			    struct drm_framebuffer *fb, const struct drm_rect *clip,
			    struct drm_format_conv_state *fmtcnv, int dst_idx)
{
	if (p4->is_native)
		p4_process_clip_native(p4, src_map, fb, clip, fmtcnv, dst_idx);
	else
		p4_process_clip_rotated(p4, src_map, fb, clip, fmtcnv, dst_idx);
}

/* ===== DRM callbacks ===== */

static void p4_enable(struct drm_simple_display_pipe *pipe,
		      struct drm_crtc_state *crtc, struct drm_plane_state *plane)
{
	struct p4_device *p4 = drm_to_p4(pipe->crtc.dev);

	p4_sender_enable(p4);
	mutex_lock(&p4->update_lock);
	p4->force_full = true;
	mutex_unlock(&p4->update_lock);
	p4_crtc_vblank_on(p4);
}

static void p4_disable(struct drm_simple_display_pipe *pipe)
{
	struct p4_device *p4 = drm_to_p4(pipe->crtc.dev);
	DBG("disable\n");

	p4_crtc_vblank_off(p4);
	/* Ensure any pending vblank work completes before shutdown */
	/* Note: screen blanking handled by dpms callback before we get here */
	p4_sender_disable(p4);
}

static void p4_update(struct drm_simple_display_pipe *pipe,
		      struct drm_plane_state *old)
{
	struct drm_plane_state *state = pipe->plane.state;
	struct drm_crtc *crtc = &pipe->crtc;
	struct p4_device *p4 = drm_to_p4(pipe->crtc.dev);
	struct drm_format_conv_state fmtcnv;
	struct iosys_map src_map;
	int idx;

	/* Handle vblank event for atomic commit completion */
	if (crtc->state->event) {
		spin_lock_irq(&crtc->dev->event_lock);
		if (drm_crtc_vblank_get(crtc) == 0)
			drm_crtc_arm_vblank_event(crtc, crtc->state->event);
		else
			drm_crtc_send_vblank_event(crtc, crtc->state->event);
		spin_unlock_irq(&crtc->dev->event_lock);
		crtc->state->event = NULL;
	}

	if (!p4_sender_is_enabled(p4) || !drm_dev_enter(&p4->drm, &idx))
		return;

	struct drm_gem_dma_object *dma_obj = drm_fb_dma_get_gem_obj(state->fb, 0);
	if (!dma_obj || !dma_obj->vaddr)
		goto out;

	/*
	 * Map DRM rotation property to our internal rotation enum.
	 * DRM_MODE_ROTATE_0/180: userspace is 720x280, we rotate 90° in SW
	 * DRM_MODE_ROTATE_90/270: userspace is 280x720, no SW rotation needed
	 *
	 * The 180° variants also set the hardware upside_down flag.
	 */
	enum p4_rotation new_rotation;
	bool hw_flip;

	switch (state->rotation & DRM_MODE_ROTATE_MASK) {
	case DRM_MODE_ROTATE_0:
		new_rotation = P4_ROT_90;  /* 720x280 -> rotate 90° -> 280x720 */
		hw_flip = false;
		break;
	case DRM_MODE_ROTATE_90:
		new_rotation = P4_ROT_0;   /* 280x720 -> no rotation -> 280x720 */
		hw_flip = false;
		break;
	case DRM_MODE_ROTATE_180:
		new_rotation = P4_ROT_270; /* 720x280 -> rotate 90° + flip -> 280x720 */
		hw_flip = true;
		break;
	case DRM_MODE_ROTATE_270:
		new_rotation = P4_ROT_180; /* 280x720 -> flip only -> 280x720 */
		hw_flip = true;
		break;
	default:
		new_rotation = P4_ROT_90;
		hw_flip = false;
		break;
	}

	/* Rotation change requires full refresh */
	bool rotation_changed = (p4->rotation != new_rotation);
	if (rotation_changed) {
		p4->rotation = new_rotation;
		p4->is_native = (new_rotation == P4_ROT_0 || new_rotation == P4_ROT_180);
	}

	/* New framebuffer requires full refresh */
	bool new_fb = !old->fb || old->fb != state->fb;

	/*
	 * Update hardware flip flag. XOR the DRM-requested flip with the
	 * user_flip setting so user can flip independently of X11/Wayland.
	 */
	p4_set_upside_down(p4, hw_flip ^ p4->user_flip);

	drm_format_conv_state_init(&fmtcnv);
	iosys_map_set_vaddr(&src_map, dma_obj->vaddr);

	/*
	 * Determine if we need full refresh.
	 * Rotation change, new FB, or force_full flag already set.
	 */
	mutex_lock(&p4->update_lock);

	bool full_refresh = p4->force_full || rotation_changed || new_fb;

	/*
	 * Both paths accumulate into dst_buf[0] and set dirty.
	 * Full refresh also sets force_full so drainer zeroes
	 * the reference buffer before diffing.
	 */
	if (full_refresh) {
		/* Use framebuffer dimensions */
		struct drm_rect full = { 0, 0, state->fb->width, state->fb->height };
		/* Clear accumulation buffer before processing full frame */
		memset(p4->dst_buf[0], 0, FB_SIZE);
		p4_process_clip(p4, &src_map, state->fb, &full, &fmtcnv, 0);
		p4->force_full = true;
	} else {
		struct drm_atomic_helper_damage_iter iter;
		struct drm_rect clip;

		drm_atomic_helper_damage_iter_init(&iter, old, state);
		while (drm_atomic_helper_damage_iter_next(&iter, &clip))
			p4_process_clip(p4, &src_map, state->fb, &clip, &fmtcnv, 0);
	}

	p4->dirty = true;

	mutex_unlock(&p4->update_lock);

	drm_format_conv_state_release(&fmtcnv);
out:
	drm_dev_exit(idx);
}

/* ===== Sysfs ===== */

static ssize_t user_flip_show(struct device *dev, struct device_attribute *attr,
			      char *buf)
{
	struct spi_device *spi = to_spi_device(dev);
	struct p4_device *p4 = spi_get_drvdata(spi);

	return sysfs_emit(buf, "%d\n", p4->user_flip ? 1 : 0);
}

static ssize_t user_flip_store(struct device *dev, struct device_attribute *attr,
			       const char *buf, size_t count)
{
	struct spi_device *spi = to_spi_device(dev);
	struct p4_device *p4 = spi_get_drvdata(spi);
	bool new_flip;
	int ret;

	ret = kstrtobool(buf, &new_flip);
	if (ret)
		return ret;

	if (p4->user_flip != new_flip) {
		p4->user_flip = new_flip;
		/*
		 * Update hardware flip state. Current DRM flip state is
		 * determined by rotation: 180°/270° modes set hw_flip=true.
		 */
		bool drm_flip = (p4->rotation == P4_ROT_180 ||
				 p4->rotation == P4_ROT_270);
		p4_set_upside_down(p4, drm_flip ^ new_flip);
	}

	return count;
}

static DEVICE_ATTR_RW(user_flip);

static struct attribute *p4_sysfs_attrs[] = {
	&dev_attr_user_flip.attr,
	NULL,
};

static const struct attribute_group p4_sysfs_group = {
	.attrs = p4_sysfs_attrs,
};

/* ===== Probe/Remove ===== */

static int p4_probe(struct spi_device *spi)
{
	struct device *dev = &spi->dev;
	struct p4_device *p4;
	int ret;

	DBG("probe: SPI %s @ %u Hz\n", dev_name(dev), spi->max_speed_hz);

	/*
	 * SPI child devices don't inherit DMA masks from their parent.
	 * Set up a 32-bit DMA mask so DRM GEM can allocate framebuffers.
	 * This follows the pattern used by repaper.c and other SPI DRM drivers.
	 */
	if (!dev->coherent_dma_mask) {
		ret = dma_coerce_mask_and_coherent(dev, DMA_BIT_MASK(32));
		if (ret) {
			dev_warn(dev, "Failed to set DMA mask: %d\n", ret);
			return ret;
		}
	}

	/* Ensure SPI mode 0 (CPOL=0, CPHA=0) and 8-bit words */
	spi->mode = SPI_MODE_0;
	spi->bits_per_word = 8;
	ret = spi_setup(spi);
	if (ret)
		return dev_err_probe(dev, ret, "SPI setup failed\n");

	/* Allocate main device struct */
	p4 = devm_drm_dev_alloc(dev, &p4_drm_driver, struct p4_device, drm);
	if (IS_ERR(p4)) {
		dev_err(dev, "failed to allocate DRM device\n");
		return PTR_ERR(p4);
	}

	p4->spi = spi;
	spi_set_drvdata(spi, p4);
	p4->blank_state = FB_BLANK_UNBLANK;
	p4->target_power = P4_POWER_NORMAL;
	p4->rotation = P4_ROT_90;  /* Default: 720x280 rotated mode */
	p4->is_native = false;     /* P4_ROT_90 requires SW rotation */
	p4->user_flip = device_property_read_bool(dev, "upside-down");
	p4->hexdump_spi = hexdump; /* From module parameter */
	mutex_init(&p4->update_lock);

	/* Create sysfs attributes */
	ret = devm_device_add_group(dev, &p4_sysfs_group);
	if (ret) {
		dev_err(dev, "failed to create sysfs group: %d\n", ret);
		return ret;
	}

	/*
	 * Allocate framebuffers (triple buffering):
	 *   src_buf    - mono conversion temporary
	 *   dst_buf[0] - accumulation buffer (p4_update writes here)
	 *   dst_buf[1] - stable buffer (vblank work copies here, then diffs)
	 *   dst_buf[2] - reference buffer (last sent state)
	 *
	 * These buffers are CPU-only (no DMA), so use normal cached memory.
	 */
	p4->src_buf = devm_kzalloc(dev, FB_SIZE, GFP_KERNEL);
	p4->dst_buf[0] = devm_kzalloc(dev, FB_SIZE, GFP_KERNEL);
	p4->dst_buf[1] = devm_kzalloc(dev, FB_SIZE, GFP_KERNEL);
	p4->dst_buf[2] = devm_kzalloc(dev, FB_SIZE, GFP_KERNEL);
	if (!p4->src_buf || !p4->dst_buf[0] || !p4->dst_buf[1] || !p4->dst_buf[2]) {
		dev_err(dev, "failed to allocate framebuffers\n");
		return -ENOMEM;
	}
	/* devm_kzalloc already zeroes memory */
	DBG("framebuffers allocated: %u bytes each (x4)\n", FB_SIZE);

	ret = p4_sender_probe(p4);
	if (ret) {
		dev_err(dev, "sender probe failed: %d\n", ret);
		return ret;
	}

	ret = p4_vblank_probe(p4);
	if (ret) {
		dev_err(dev, "vblank probe failed: %d\n", ret);
		goto err_sender;
	}

	ret = p4_backlight_probe(p4);
	if (ret) {
		dev_err(dev, "backlight probe failed: %d\n", ret);
		goto err_vblank;
	}

	ret = drmm_mode_config_init(&p4->drm);
	if (ret) {
		dev_err(dev, "mode config init failed: %d\n", ret);
		goto err_backlight;
	}

	p4->drm.mode_config.funcs = &mode_funcs;
	/*
	 * Allow both 720x280 and 280x720 framebuffers.
	 * xrandr rotation creates a rotated framebuffer when rotation
	 * is set to 90° or 270°.
	 */
	p4->drm.mode_config.min_width = P4_HEIGHT;
	p4->drm.mode_config.max_width = P4_WIDTH;
	p4->drm.mode_config.min_height = P4_HEIGHT;
	p4->drm.mode_config.max_height = P4_WIDTH;

	drm_connector_helper_add(&p4->connector, &conn_helper);
	ret = drm_connector_init(&p4->drm, &p4->connector, &conn_funcs,
				 DRM_MODE_CONNECTOR_SPI);
	if (ret) {
		dev_err(dev, "connector init failed: %d\n", ret);
		goto err_backlight;
	}
	/* Enable hotplug detection - we signal events from drainer thread */
	p4->connector.polled = DRM_CONNECTOR_POLL_HPD;

	ret = drm_simple_display_pipe_init(&p4->drm, &p4->pipe, &pipe_funcs,
					   p4_formats, ARRAY_SIZE(p4_formats),
					   NULL, &p4->connector);
	if (ret) {
		dev_err(dev, "pipe init failed: %d\n", ret);
		goto err_backlight;
	}

	drm_plane_enable_fb_damage_clips(&p4->pipe.plane);
	drm_plane_create_rotation_property(&p4->pipe.plane,
					   DRM_MODE_ROTATE_0,
					   DRM_MODE_ROTATE_0 | DRM_MODE_ROTATE_90 |
					   DRM_MODE_ROTATE_180 | DRM_MODE_ROTATE_270);
	drm_mode_config_reset(&p4->drm);

	ret = drm_vblank_init(&p4->drm, 1);
	if (ret) {
		dev_err(dev, "vblank init failed: %d\n", ret);
		goto err_backlight;
	}

	ret = drm_dev_register(&p4->drm, 0);
	if (ret) {
		dev_err(dev, "DRM register failed: %d\n", ret);
		goto err_backlight;
	}

	/*
	 * Apply initial user_flip from device tree. At this point rotation
	 * is P4_ROT_90 (no hw_flip), so effective flip = user_flip.
	 */
	if (p4->user_flip)
		p4_set_upside_down(p4, true);

	/*
	 * Set up fbdev emulation. Newer kernels (6.12+) prefer drm_client_setup()
	 * with DRM_FBDEV_DMA_DRIVER_OPS, but drm_fbdev_dma_setup() still works.
	 */
	drm_fbdev_dma_setup(&p4->drm, 32);

	dev_info(dev, "registered /dev/dri/card%d (%ux%u @ %u Hz SPI)%s\n",
		 p4->drm.primary->index, P4_WIDTH, P4_HEIGHT,
		 spi->max_speed_hz, p4->user_flip ? " [flipped]" : "");
	return 0;

err_backlight:
	p4_backlight_remove(p4);
err_vblank:
	p4_vblank_remove(p4);
err_sender:
	p4_sender_remove(p4);
	return ret;
}

static void p4_remove(struct spi_device *spi)
{
	struct p4_device *p4 = spi_get_drvdata(spi);

	/*
	 * Unplug DRM first - this prevents new operations from starting
	 * and marks the device as gone.
	 */
	if (!drm_dev_is_unplugged(&p4->drm))
		drm_dev_unplug(&p4->drm);

	/*
	 * Shutdown DRM while vblank and sender are still functional.
	 * This allows drm_atomic_helper_shutdown() to complete its
	 * final commit without timing out waiting for vblank.
	 */
	drm_atomic_helper_shutdown(&p4->drm);

	/* Now safe to turn off vblank */
	drm_crtc_vblank_off(&p4->pipe.crtc);

	/*
	 * Stop sender/drainer after DRM shutdown is complete.
	 * The drainer thread might call drm_kms_helper_hotplug_event(),
	 * which would crash if DRM is being torn down.
	 */
	p4_sender_remove(p4);

	p4_backlight_remove(p4);
	p4_vblank_remove(p4);
}

static void p4_shutdown(struct spi_device *spi)
{
	struct p4_device *p4 = spi_get_drvdata(spi);

	drm_atomic_helper_shutdown(&p4->drm);
	p4_backlight_remove(p4);
	p4_vblank_remove(p4);
	p4_sender_remove(p4);
}

static int __init p4_module_init(void)
{
	int ret;

	pr_info("p4-rotate: module loading\n");
	ret = spi_register_driver(&p4_spi_driver);
	if (ret)
		pr_err("p4-rotate: spi_register_driver failed: %d\n", ret);
	else
		pr_info("p4-rotate: driver registered, waiting for device match\n");
	return ret;
}

static void __exit p4_module_exit(void)
{
	pr_info("p4-rotate: module unloading\n");
	spi_unregister_driver(&p4_spi_driver);
}

module_init(p4_module_init);
module_exit(p4_module_exit);

MODULE_DESCRIPTION("DRM driver for P4 rotated monochrome SPI display");
MODULE_LICENSE("GPL");

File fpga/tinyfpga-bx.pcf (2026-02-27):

###################
# Clock and Lamp: #
###################

# In: 16MHz from resonator
set_io -nowarn CLK16 B2

# Out: Status Lamp
set_io -nowarn STATUS B3

##############
# Slave SPI: #
##############

# In: SPI nCS (221/rpi24/GPIO8-CE0)
set_io -nowarn SPI_NCS A2

# In: SPI SCK (3B/rpi23/GPIO11-SCLK0)
set_io -nowarn SPI_SK C1

# In: SPI MISO (7A/rpi21/GPIO9-MISO0)
set_io -nowarn SPI_DI D2

# Out: SPI MOSI (10A/rpi19/GPIO10-MOSI0)
set_io -nowarn SPI_DO D1

###################
# Misc. Host I/O: #
###################

# In: nRESET (224/rpi33/GPIO13)
set_io -nowarn NRESET A1

# Out: Device Ready (3A/rpi31/GPIO6)
set_io -nowarn DEV_RDY B1

# In: Enable (2A/rpi29/GPIO5)
set_io -nowarn ENABLE C2

# Out: Cold (10B/rpi15/GPIO22)
set_io -nowarn COLD E1

# Out: VBlank (26A/rpi13/GPIO27)
set_io -nowarn VBLANK G2

# In: nSLEEP (55/rpi11/GPIO17)
set_io -nowarn NSLEEP J1

############################
# Private Eye (3.3v<->5v): #
############################

# Out: Private Eye Clock (13A)
set_io -nowarn PE_CLK E2

# Out: Private Eye Data (54)
set_io -nowarn PE_DAT H1

# Out: Private Eye nBOS (116)
set_io -nowarn PE_NBOS A9

# In: Private Eye nRDY (111)
set_io -nowarn PE_NRDY H9

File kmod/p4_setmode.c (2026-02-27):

// SPDX-License-Identifier: GPL-2.0
/*
 * p4_setmode - Set display rotation using atomic modesetting
 *
 * Usage: p4_setmode [normal | left | right | inverted]
 *        p4_setmode --list
 *
 * This sets the DRM rotation property, which is what xrandr uses.
 * - normal:   0° rotation (720x280 framebuffer, driver rotates 90°)
 * - left:     90° rotation (280x720 framebuffer, no driver rotation)
 * - inverted: 180° rotation (720x280 + hw flip)
 * - right:    270° rotation (280x720 + hw flip)
 */

#include <stdio.h>
#include <stdlib.h>
#include <string.h>
#include <fcntl.h>
#include <unistd.h>
#include <errno.h>
#include <stdint.h>
#include <sys/ioctl.h>
#include <sys/mman.h>
#include <xf86drm.h>
#include <xf86drmMode.h>
#include <drm_fourcc.h>
#include <drm_mode.h>

#include "display.h"

static int find_p4_device(void)
{
	char path[64];
	int fd;
	drmVersionPtr ver;

	for (int i = 0; i < 16; i++) {
		snprintf(path, sizeof(path), "/dev/dri/card%d", i);
		fd = open(path, O_RDWR);
		if (fd < 0)
			continue;

		ver = drmGetVersion(fd);
		if (ver) {
			int match = (strcmp(ver->name, "p4_display") == 0);
			drmFreeVersion(ver);
			if (match) {
				if (drmSetClientCap(fd, DRM_CLIENT_CAP_ATOMIC, 1) < 0) {
					fprintf(stderr, "Warning: atomic not supported\n");
				}
				if (drmSetClientCap(fd, DRM_CLIENT_CAP_UNIVERSAL_PLANES, 1) < 0) {
					fprintf(stderr, "Warning: universal planes not supported\n");
				}
				return fd;
			}
		}
		close(fd);
	}
	return -1;
}

/* Get property ID and current value by name */
static uint32_t get_prop_id(int fd, uint32_t obj_id, uint32_t obj_type,
			    const char *name, uint64_t *value)
{
	drmModeObjectProperties *props = drmModeObjectGetProperties(fd, obj_id, obj_type);
	if (!props)
		return 0;

	uint32_t prop_id = 0;
	for (uint32_t i = 0; i < props->count_props; i++) {
		drmModePropertyRes *prop = drmModeGetProperty(fd, props->props[i]);
		if (!prop)
			continue;
		if (strcmp(prop->name, name) == 0) {
			prop_id = prop->prop_id;
			if (value)
				*value = props->prop_values[i];
			drmModeFreeProperty(prop);
			break;
		}
		drmModeFreeProperty(prop);
	}
	drmModeFreeObjectProperties(props);
	return prop_id;
}

static void list_info(int fd)
{
	drmModeRes *res;
	drmModeConnector *conn;
	drmModePlaneRes *plane_res;

	res = drmModeGetResources(fd);
	if (!res) {
		fprintf(stderr, "Failed to get DRM resources\n");
		return;
	}

	printf("Connectors: %d\n", res->count_connectors);

	for (int i = 0; i < res->count_connectors; i++) {
		conn = drmModeGetConnector(fd, res->connectors[i]);
		if (!conn)
			continue;

		printf("\nConnector %u: %s\n",
		       conn->connector_id,
		       conn->connection == DRM_MODE_CONNECTED ? "connected" : "disconnected");
		printf("  Modes: %d\n", conn->count_modes);

		for (int j = 0; j < conn->count_modes; j++) {
			drmModeModeInfo *mode = &conn->modes[j];
			printf("    %dx%d @ %dHz%s\n",
			       mode->hdisplay, mode->vdisplay,
			       mode->vrefresh,
			       (mode->type & DRM_MODE_TYPE_PREFERRED) ? " (preferred)" : "");
		}

		drmModeFreeConnector(conn);
	}

	/* List planes and their rotation property */
	plane_res = drmModeGetPlaneResources(fd);
	if (plane_res) {
		printf("\nPlanes: %d\n", plane_res->count_planes);
		for (uint32_t i = 0; i < plane_res->count_planes; i++) {
			drmModePlane *plane = drmModeGetPlane(fd, plane_res->planes[i]);
			if (!plane)
				continue;

			uint64_t rotation = 0;
			uint32_t rot_prop = get_prop_id(fd, plane->plane_id,
						       DRM_MODE_OBJECT_PLANE, "rotation", &rotation);

			printf("  Plane %u: rotation prop=%u, value=%lu\n",
			       plane->plane_id, rot_prop, (unsigned long)rotation);

			drmModeFreePlane(plane);
		}
		drmModeFreePlaneResources(plane_res);
	}

	drmModeFreeResources(res);
}

/* Fill buffer with test pattern */
static void fill_pattern(uint32_t *buf, int width, int height, int pitch_bytes, const char *pattern)
{
	int pitch = pitch_bytes / 4;
	uint32_t white = 0x00FFFFFF;
	uint32_t black = 0x00000000;

	for (int y = 0; y < height; y++) {
		for (int x = 0; x < width; x++) {
			uint32_t color;
			if (!pattern || strcmp(pattern, "black") == 0) {
				color = black;
			} else if (strcmp(pattern, "white") == 0) {
				color = white;
			} else if (strcmp(pattern, "checker") == 0) {
				color = ((x / 8) + (y / 8)) % 2 ? white : black;
			} else if (strcmp(pattern, "vstripes") == 0) {
				color = (x / 8) % 2 ? white : black;
			} else if (strcmp(pattern, "hstripes") == 0) {
				color = (y / 8) % 2 ? white : black;
			} else if (strcmp(pattern, "arrow") == 0) {
				/*
				 * Arrow pointing RIGHT with distinct corner markers.
				 * All dimensions are multiples of 8 for clean byte-aligned rendering.
				 * 
				 * In source framebuffer (before any rotation):
				 *   TL: small square
				 *   TR: horizontal bar (wider than tall)
				 *   BL: vertical bar (taller than wide)
				 *   BR: large square
				 *   Center: arrow pointing right
				 */
				
				int m = 8;  /* margin from edge */
				
				/* TL: small square 24x24 */
				int in_tl = (x >= m && x < m + 24 &&
				             y >= m && y < m + 24);
				
				/* TR: horizontal bar 48x16 */
				int in_tr = (x >= width - m - 48 && x < width - m &&
				             y >= m && y < m + 16);
				
				/* BL: vertical bar 16x48 */
				int in_bl = (x >= m && x < m + 16 &&
				             y >= height - m - 48 && y < height - m);
				
				/* BR: large square 40x40 */
				int in_br = (x >= width - m - 40 && x < width - m &&
				             y >= height - m - 40 && y < height - m);
				
				/* Arrow - simple right-pointing shape */
				int cx = width / 2;
				int cy = height / 2;
				
				/* Shaft: rectangle 64x16 */
				int in_shaft = (x >= cx - 64 && x < cx &&
				                y >= cy - 8 && y < cy + 8);
				
				/* Head: triangle using horizontal bands */
				int in_head = 0;
				if (x >= cx && x < cx + 48) {
					int progress = x - cx;  /* 0 at base, 48 at tip */
					int half_h = 32 - (progress * 32 / 48);
					in_head = (y >= cy - half_h && y < cy + half_h);
				}
				
				color = (in_tl || in_tr || in_bl || in_br || in_shaft || in_head) ? black : white;
			} else {
				color = black;
			}
			buf[y * pitch + x] = color;
		}
	}
}

/* Global for stdin data */
static uint8_t *g_stdin_data = NULL;
static size_t g_stdin_size = 0;
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

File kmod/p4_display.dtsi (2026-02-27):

// SPDX-License-Identifier: GPL-2.0
/*
 * Device Tree Overlay for P4 display on RPi SPI0
 * Generated from p4_pins.conf - do not edit directly
 * Regenerate with: make dtsi
 *
 * Compile:
 *   dtc -@ -I dts -O dtb -o p4_display.dtbo p4_display.dtsi
 *
 * Install:
 *   sudo cp p4_display.dtbo /boot/overlays/
 *
 * Enable in /boot/config.txt:
 *   dtoverlay=p4_display
 *
 * Pin Configuration:
 *   ENABLE  = GPIO5
 *   READY   = GPIO6
 *   COLD    = GPIO22
 *   NRESET  = GPIO13 (active low)
 *   NSLEEP  = GPIO17 (active low)
 *   VSYNC   = GPIO27
 */

/dts-v1/;
/plugin/;

/ {
	compatible = "brcm,bcm2711";

	/* Enable SPI0 */
	fragment@0 {
		target = <&spi0>;
		__overlay__ {
			status = "okay";
			#address-cells = <1>;
			#size-cells = <0>;

			/* Disable existing spidev@0 to free chipselect 0 */
			spidev@0 {
				status = "disabled";
			};

			p4_display: p4-display@0 {
				compatible = "example,p4-display";
				reg = <0>;  /* CE0 */
				spi-max-frequency = <28000000>;
				p4-overlay-id = "v130";
				/* SPI mode 0 (CPOL=0, CPHA=0) - no spi-cpol/spi-cpha */

				enable-gpios = <&gpio 5 0>;
				ready-gpios = <&gpio 6 0>;
				cold-gpios = <&gpio 22 0>;
				nreset-gpios = <&gpio 13 0>;  /* active-low HW, flag=0: driver uses physical values */
				nsleep-gpios = <&gpio 17 0>;  /* active-low HW, flag=0: driver uses physical values */
				vsync-gpios = <&gpio 27 0>;

				/* upside-down; */  /* Uncomment for 180° flip at boot */
			};
		};
	};

	/* Configure GPIO pin modes */
	fragment@1 {
		target = <&gpio>;
		__overlay__ {
			p4_pins: p4_pins {
				brcm,pins = <5 6 22 13 17 27>;
				brcm,function = <1 0 0 1 1 0>;  /* out, in, in, out, out, in */
				brcm,pull = <0 0 0 0 0 0>;      /* none */
			};
		};
	};

	/* Parameters for runtime customization */
	__overrides__ {
		speed = <&p4_display>, "spi-max-frequency:0";
		enable_pin = <&p4_display>, "enable-gpios:4";
		ready_pin = <&p4_display>, "ready-gpios:4";
		cold_pin = <&p4_display>, "cold-gpios:4";
		nreset_pin = <&p4_display>, "nreset-gpios:4";
		nsleep_pin = <&p4_display>, "nsleep-gpios:4";
		vsync_pin = <&p4_display>, "vsync-gpios:4";
	};
};

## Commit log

2026-02-27 First publication.
    [p4.kicad_pcb, p4.kicad_sch]
2026-02-27 Revise README for Private Eye P4 interface board
    Updated project title and added images to README.
2026-02-27 Improve README links for interface PCB and code
    Updated links in the requirements section for clarity.
2026-02-27 Update README with display and driver information
    Clarified display rotation and added details about driver features and performance.
2026-02-27 Enhance README with iCE40 SPI controller details
    Added details about the iCE40 clock speed and buffer data capabilities.
2026-02-28 Update README with additional P4 resolution details
    Clarify details about the P4's capabilities and limitations regarding horizontal resolutions and framebuffer usage.
2026-02-28 Enhance README with detailed driver and FPGA info
    Updated README to include detailed descriptions of the Linux kernel driver, power management, display rotation, and FPGA firmware functionalities.
2026-02-28 Update README with detailed PCB and connector info
    Clarified details about the interface PCB and connector specifications.
2026-02-28 Add public domain notice for FPGA code and PCB
2026-02-28 Clarify interface board and FPGA requirements in README
    Updated README to clarify the interface board and TinyFPGA BX requirements.
2026-03-02 Improve README animation description
    Clarified description of display refresh rate and framebuffer visibility.
